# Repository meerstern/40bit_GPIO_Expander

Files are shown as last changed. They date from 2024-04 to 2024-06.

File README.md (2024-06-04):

# 40Bit GPIO Expander基板

## 概要
 * 本基板は[NXP PCA9506DGG][1]を搭載した40ポートのIO拡張基板です  
 * アドレス変更で同⼀のI2Cバスで最⼤8つ、合計320ポートのIOに拡張することが可能です  
 * 各GPIOはソースで最⼤10mA、シンクで最⼤15mA流すことが可能です  
 * LED等を直接駆動させることが可能です
 * 操作パネル等のGPIOに最適です  
 * 5V/3.3V電源に対応しています  
 * I2CポートにはGrove互換コネクタを搭載しています  
 * デフォルトのI2Cアドレスは0x20(7bit)です  
 * アドレス設定ピンはすべてGNDに接続されています  
 * RESETピンを除く、全GPIO、INT、OEピンにアクセス可能です
 * Arduinoのサンプルプログラムを用意しています   

## 注意点
 * PCA9506DGGはプルアップ抵抗を内蔵していません  
 * スイッチ等の入力で使用する場合は回路に応じて必ずプルダウンかプルアップ抵抗を外付けしてください  
 * 本基板の裏面にプルアップ抵抗の実装パターンがあります  
 * スイッチ等の入力で使用する場合に必要に応じて10k~100kΩ程度の1608サイズ抵抗を実装してください  

  [1]: https://www.nxp.com/products/interfaces/ic-spi-i3c-interface-devices/general-purpose-i-o-gpio/40-bit-ic-bus-i-o-port-with-reset-oe-and-int:PCA9505_06

## 外観
* サイズ 約27mm x約60mm(コネクタ含めず)
* サイズ 約27mm x約63mm(コネクタ含め)
  
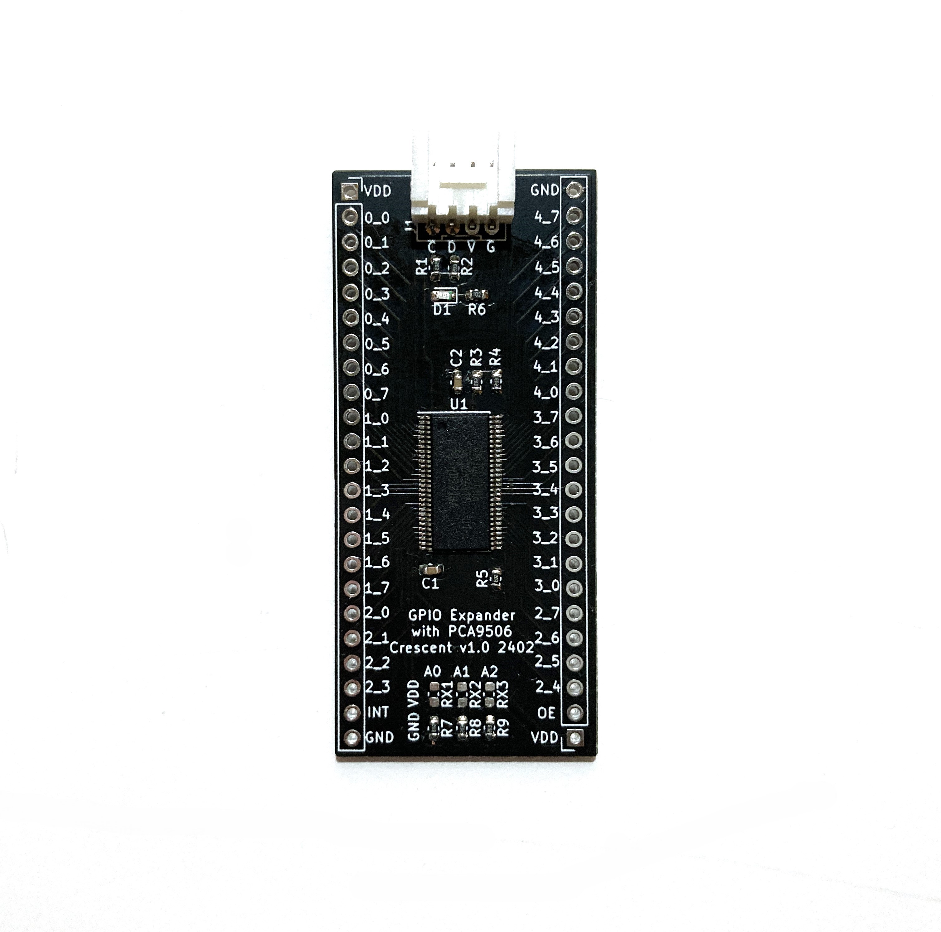
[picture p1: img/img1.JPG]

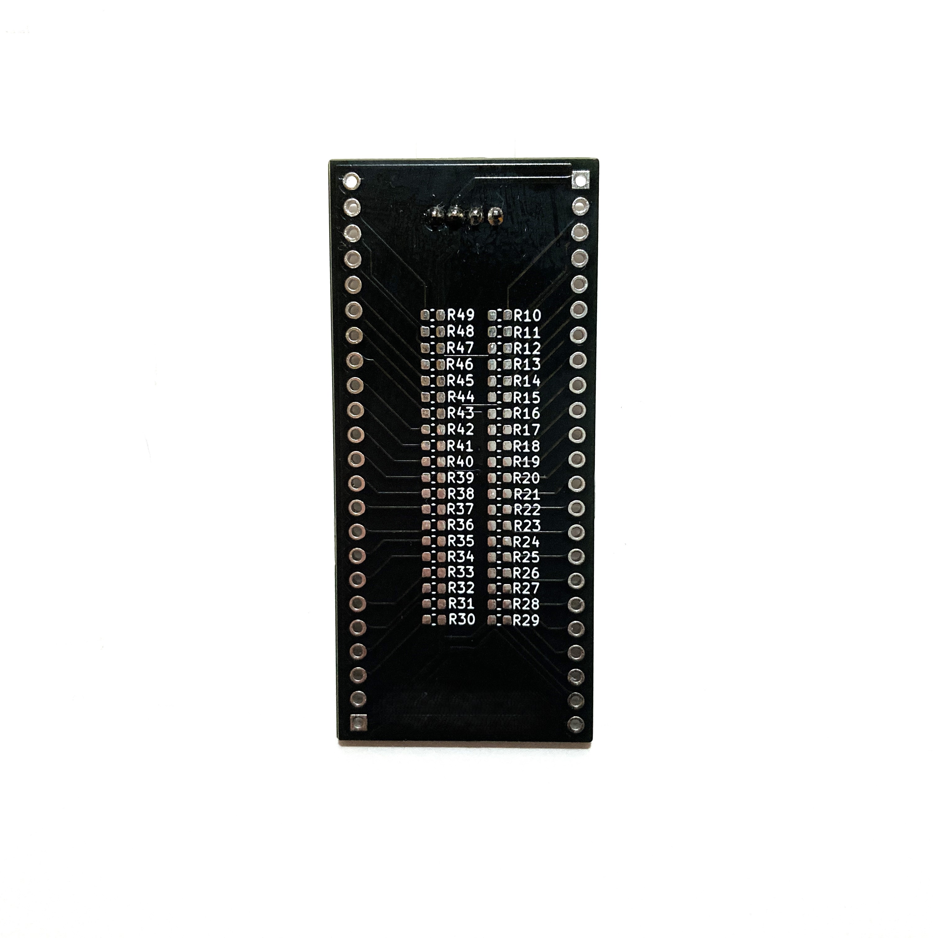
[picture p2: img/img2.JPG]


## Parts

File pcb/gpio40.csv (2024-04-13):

ID | 参照記号 | パッケージ | 数 | 名称 | Supplier and ref
1 | U1 | TSSOP-56_6.1x14mm_P0.5mm | 1 | PCA9506
2 | RX3,RX2,RX1,R9,R8,R7,R5,R4,R3,R2,R1 | R_0603_1608Metric | 11 | 10k
3 | R49,R48,R47,R46,R45,R44,R43,R42,R41,R40,R39,R38,R37,R36,R35,R34,R33,R32,R31,R30,R29,R28,R27,R26,R25,R24,R23,R22,R21,R20,R19,R18,R17,R16,R15,R14,R13,R12,R11,R10 | R_0603_1608Metric | 40 | 100k
4 | R6 | R_0603_1608Metric | 1 | 2.1k
5 | J3,J2 | PinSocket_1x23_P2.54mm_Vertical | 2 | Conn_01x23
6 | J1 | GROVE | 1 | Grove
7 | D1 | D_0603_1608Metric | 1 | LED_ALT
8 | C2,C1 | C_0603_1608Metric | 2 | 0.1u

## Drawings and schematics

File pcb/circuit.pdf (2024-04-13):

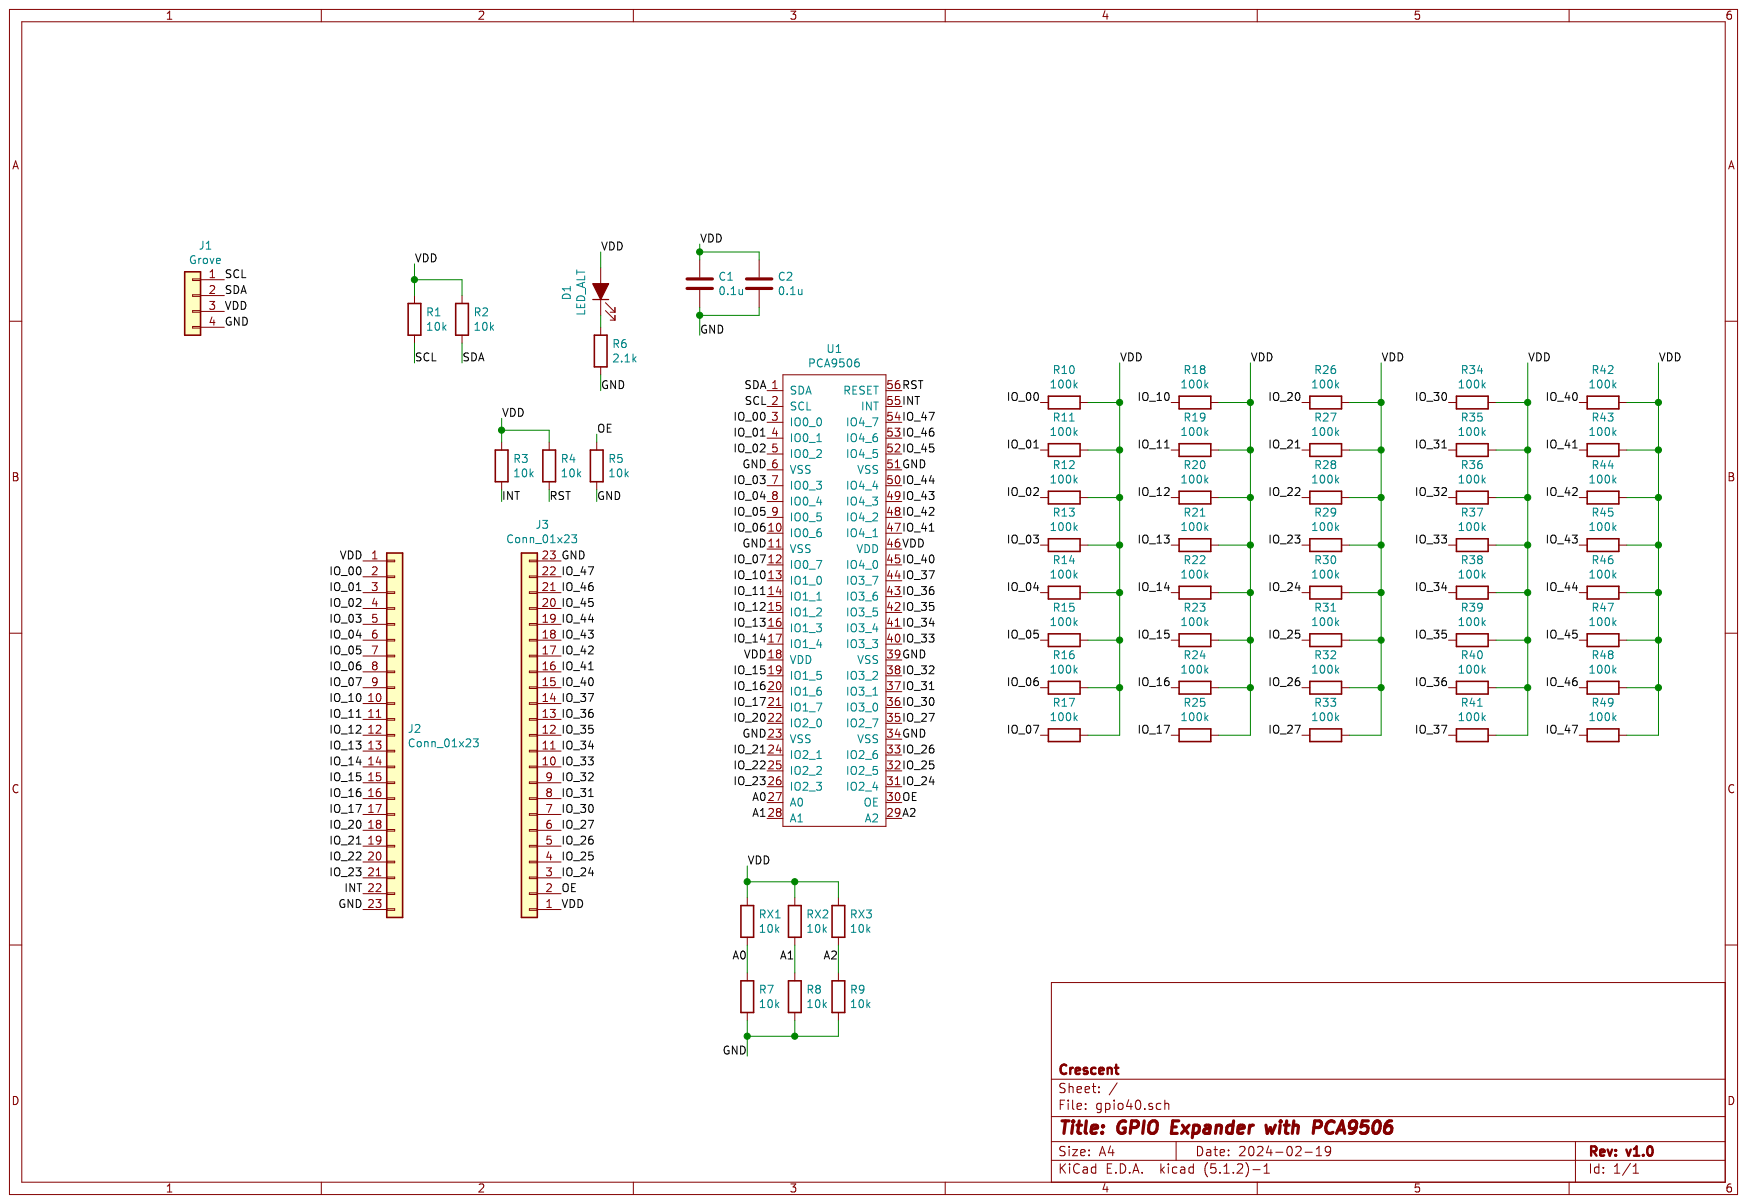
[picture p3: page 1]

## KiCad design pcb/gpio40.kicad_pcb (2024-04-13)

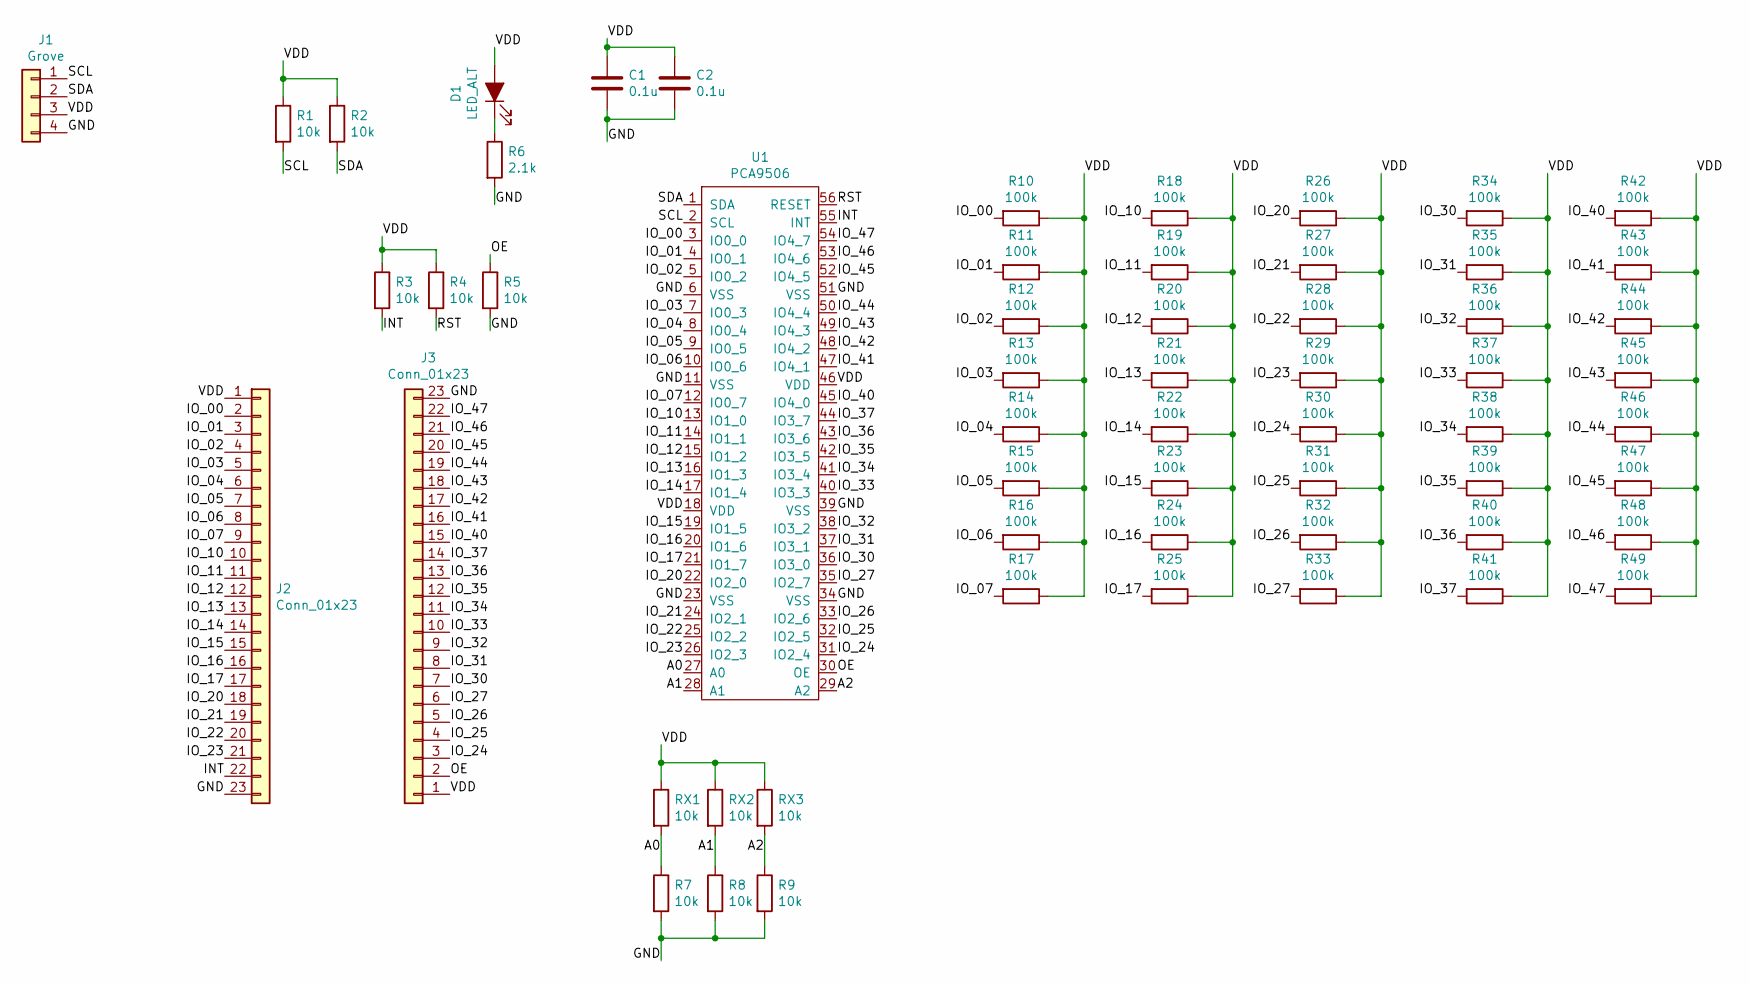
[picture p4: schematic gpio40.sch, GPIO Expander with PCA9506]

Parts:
C1, C2: 0.1u; C_0603_1608Metric
D1: LED_ALT; D_0603_1608Metric
J1: Grove; GROVE
J2, J3: Conn_01x23; PinSocket_1x23_P2.54mm_Vertical
R1, R2, R3, R4, R5, R7, R8, R9: 10k; R_0603_1608Metric
R6: 2.1k; R_0603_1608Metric
R10, R11, R12, R13, R14, R15, R16, R17, R18, R19, R20, R21, R22, R23, R24, R25, R26, R27, R28, R29, R30, R31, R32, R33, R34, R35, R36, R37, R38, R39, R40, R41, R42, R43, R44, R45, R46, R47, R48, R49: 100k; R_0603_1608Metric
RX1, RX2, RX3: 10k; R_0603_1608Metric
U1: PCA9506; TSSOP-56_6.1x14mm_P0.5mm

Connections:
/A0: R7.1, RX1.2, U1.27 (A0)
/A1: R8.1, RX2.2, U1.28 (A1)
/A2: R9.1, RX3.2, U1.29 (A2)
/GND: C1.2, C2.2, J1.4, J2.23, J3.23, R5.2, R6.2, R7.2, R8.2, R9.2, U1.6 (VSS), U1.11 (VSS), U1.23 (VSS), U1.34 (VSS), U1.39 (VSS), U1.51 (VSS)
/INT: J2.22, R3.2, U1.55 (INT)
/IO_00: J2.2, R10.2, U1.3 (IO0_0)
/IO_01: J2.3, R11.2, U1.4 (IO0_1)
/IO_02: J2.4, R12.2, U1.5 (IO0_2)
/IO_03: J2.5, R13.2, U1.7 (IO0_3)
/IO_04: J2.6, R14.2, U1.8 (IO0_4)
/IO_05: J2.7, R15.2, U1.9 (IO0_5)
/IO_06: J2.8, R16.2, U1.10 (IO0_6)
/IO_07: J2.9, R17.2, U1.12 (IO0_7)
/IO_10: J2.10, R18.2, U1.13 (IO1_0)
/IO_11: J2.11, R19.2, U1.14 (IO1_1)
/IO_12: J2.12, R20.2, U1.15 (IO1_2)
/IO_13: J2.13, R21.2, U1.16 (IO1_3)
/IO_14: J2.14, R22.2, U1.17 (IO1_4)
/IO_15: J2.15, R23.2, U1.19 (IO1_5)
/IO_16: J2.16, R24.2, U1.20 (IO1_6)
/IO_17: J2.17, R25.2, U1.21 (IO1_7)
/IO_20: J2.18, R26.2, U1.22 (IO2_0)
/IO_21: J2.19, R27.2, U1.24 (IO2_1)
/IO_22: J2.20, R28.2, U1.25 (IO2_2)
/IO_23: J2.21, R29.2, U1.26 (IO2_3)
/IO_24: J3.3, R30.2, U1.31 (IO2_4)
/IO_25: J3.4, R31.2, U1.32 (IO2_5)
/IO_26: J3.5, R32.2, U1.33 (IO2_6)
/IO_27: J3.6, R33.2, U1.35 (IO2_7)
/IO_30: J3.7, R34.2, U1.36 (IO3_0)
/IO_31: J3.8, R35.2, U1.37 (IO3_1)
/IO_32: J3.9, R36.2, U1.38 (IO3_2)
/IO_33: J3.10, R37.2, U1.40 (IO3_3)
/IO_34: J3.11, R38.2, U1.41 (IO3_4)
/IO_35: J3.12, R39.2, U1.42 (IO3_5)
/IO_36: J3.13, R40.2, U1.43 (IO3_6)
/IO_37: J3.14, R41.2, U1.44 (IO3_7)
/IO_40: J3.15, R42.2, U1.45 (IO4_0)
/IO_41: J3.16, R43.2, U1.47 (IO4_1)
/IO_42: J3.17, R44.2, U1.48 (IO4_2)
/IO_43: J3.18, R45.2, U1.49 (IO4_3)
/IO_44: J3.19, R46.2, U1.50 (IO4_4)
/IO_45: J3.20, R47.2, U1.52 (IO4_5)
/IO_46: J3.21, R48.2, U1.53 (IO4_6)
/IO_47: J3.22, R49.2, U1.54 (IO4_7)
/OE: J3.2, R5.1, U1.30 (OE)
/RST: R4.2, U1.56 (RESET)
/SCL: J1.1, R1.2, U1.2 (SCL)
/SDA: J1.2, R2.2, U1.1 (SDA)
/VDD: C1.1, C2.1, D1.2 (A), J1.3, J2.1, J3.1, R1.1, R2.1, R3.1, R4.1, R10.1, R11.1, R12.1, R13.1, R14.1, R15.1, R16.1, R17.1, R18.1, R19.1, R20.1, R21.1, R22.1, R23.1, R24.1, R25.1, R26.1, R27.1, R28.1, R29.1, R30.1, R31.1, R32.1, R33.1, R34.1, R35.1, R36.1, R37.1, R38.1, R39.1, R40.1, R41.1, R42.1, R43.1, R44.1, R45.1, R46.1, R47.1, R48.1, R49.1, RX1.1, RX2.1, RX3.1, U1.18 (VDD), U1.46 (VDD)
unnamed: D1.1 (K), R6.1

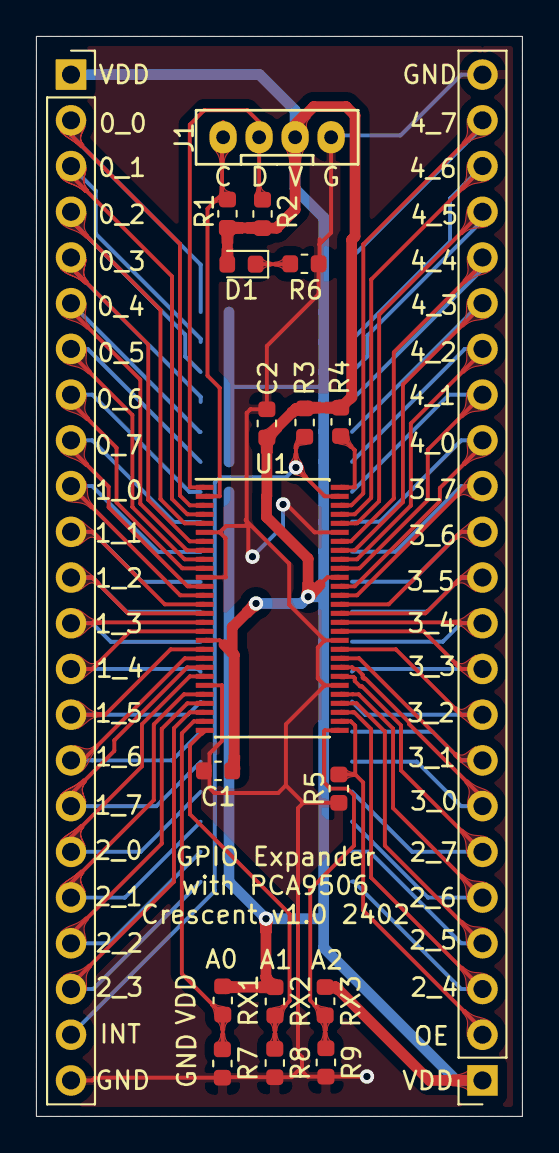
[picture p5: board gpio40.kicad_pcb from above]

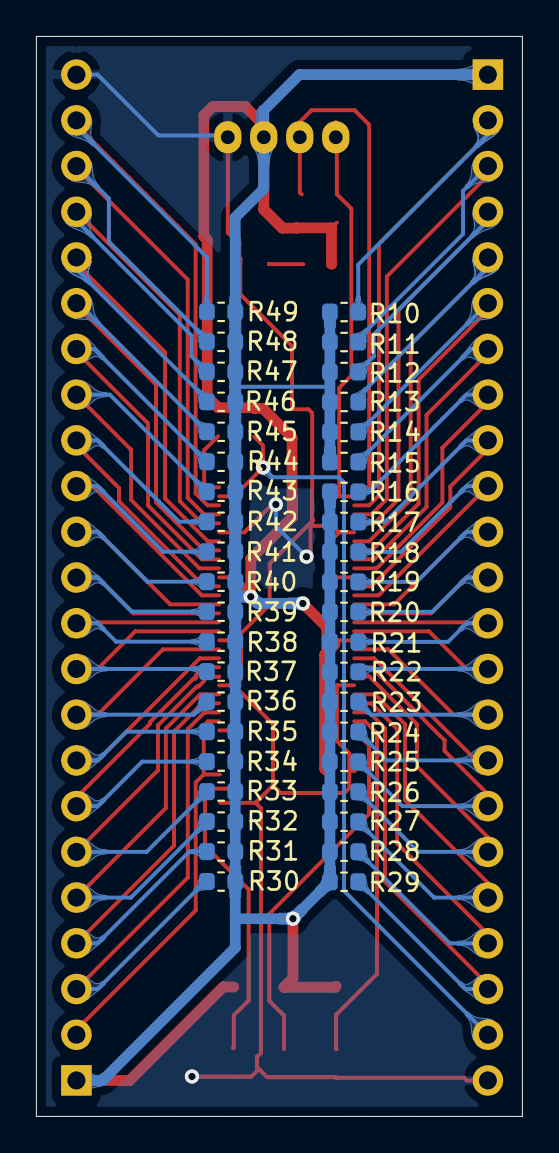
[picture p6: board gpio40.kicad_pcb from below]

Board: 2 copper layers, 27.0 x 60.0 mm, 59 parts (40 on the bottom side), 51 nets.

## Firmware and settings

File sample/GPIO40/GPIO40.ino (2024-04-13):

/*
 *  	GPIO40.ino
 *
 *  Copyright (c) 2024
 *  K.Watanabe, Crescentt
 *  Released under the MIT license
 *  http://opensource.org/licenses/mit-license.php
 *
 */

#include <Arduino.h>
#include <Wire.h>
#include "PCA9506.h"


PCA9506 GPIO40;




uint8_t wdata[5];
uint8_t rdata[5];
uint16_t bit=1;

void setup()
{
	uint8_t io_dir[5];
	//Set Device Address
	GPIO40.Init(PCA9506_ADDR_000);

	//IO00~IO27 Input
	//IO30~IO47 Output
	io_dir[0]=0xFF;//IO0
	io_dir[1]=0xFF;//IO1
	io_dir[2]=0xFF;//IO2
	io_dir[3]=0x00;//IO3
	io_dir[4]=0x00;//IO4
	GPIO40.SetIODirByte(io_dir[0],io_dir[1],io_dir[2],io_dir[3],io_dir[4]);
	//Check Connection
	if(!GPIO40.isConnected())
	{
    	Serial.println("PCA9506 Not Found!");
    	while(1);
	}

}


void loop()
{
	
	wdata[3]=bit&0xFF;
	wdata[4]=(bit>>8)&0xFF;
	bit=bit<<1;
	if(bit==0)
		bit=1;	
	
	//Write IO
	GPIO40.WriteIOByte( wdata[0], wdata[1], wdata[2], wdata[3], wdata[4]);
	
	//Read IO
	GPIO40.ReadIOByte( &rdata[0], &rdata[1], &rdata[2], &rdata[3], &rdata[4]);
	
	Serial.print(rdata[0]);
	Serial.print(", ");
	Serial.print(rdata[1]);
	Serial.print(", ");
	Serial.print(rdata[2]);
	Serial.println("");
	
	delay(100);
}

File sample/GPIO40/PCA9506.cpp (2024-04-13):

/*
 *  	PCA9506.c
 *
 *  Copyright (c) 2024
 *  K.Watanabe, Crescentt
 *  Released under the MIT license
 *  http://opensource.org/licenses/mit-license.php
 *
 */
#include <Arduino.h>
#include <Wire.h>
#include "PCA9506.h"


void PCA9506::Begin(uint8_t addr)
{
	dev_addr = addr;
	Wire.begin();
}

bool PCA9506::IsConnected()
{
	int8_t error;
	Wire.beginTransmission(dev_addr);
		error = Wire.endTransmission();
	if( error == 0 )
	return true;
	else
	return false;
}


void PCA9506::SetIODirByte( uint8_t io0, uint8_t io1, uint8_t io2, uint8_t io3, uint8_t io4 )
{
	Wire.beginTransmission(dev_addr);
	Wire.write(PCA9506_IOC0_REG | PCA9506_CMD_REG);
	Wire.write(io0);
	Wire.write(io1);
	Wire.write(io2);
	Wire.write(io3);
	Wire.write(io4);
	Wire.endTransmission();
}


void PCA9506::ReadIOByte( uint8_t *io0, uint8_t *io1, uint8_t *io2, uint8_t *io3, uint8_t *io4)
{
	uint8_t rsize = 5;
	Wire.beginTransmission(dev_addr);
	Wire.write(PCA9506_IP0_REG | PCA9506_CMD_REG);
	Wire.endTransmission();
	Wire.requestFrom(dev_addr, rsize);
	*io0 = Wire.read();
	*io1 = Wire.read();
	*io2 = Wire.read();
	*io3 = Wire.read();
	*io4 = Wire.read();
}


void PCA9506::WriteIOByte( uint8_t io0, uint8_t io1, uint8_t io2, uint8_t io3, uint8_t io4 )
{
	Wire.beginTransmission(dev_addr);
	Wire.write(PCA9506_OP0_REG | PCA9506_CMD_REG);
	Wire.write(io0);
	Wire.write(io1);
	Wire.write(io2);
	Wire.write(io3);
	Wire.write(io4);
	Wire.endTransmission();
}
